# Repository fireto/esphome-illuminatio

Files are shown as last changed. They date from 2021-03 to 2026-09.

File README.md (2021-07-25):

# esphome-illuminatio
Dimmable LED drivers controller based on ESP Home with HomeAssistant integration via MQTT

in order to compile and deploy this project you need to get https://esphome.io

```podman run --rm -v "${PWD}":/config --device=/dev/ttyUSB0 -it esphome/esphome ./illuminatio.yml run```

BOM

LED Drivers connector cable:
 CS-DSDMDB15MM-010

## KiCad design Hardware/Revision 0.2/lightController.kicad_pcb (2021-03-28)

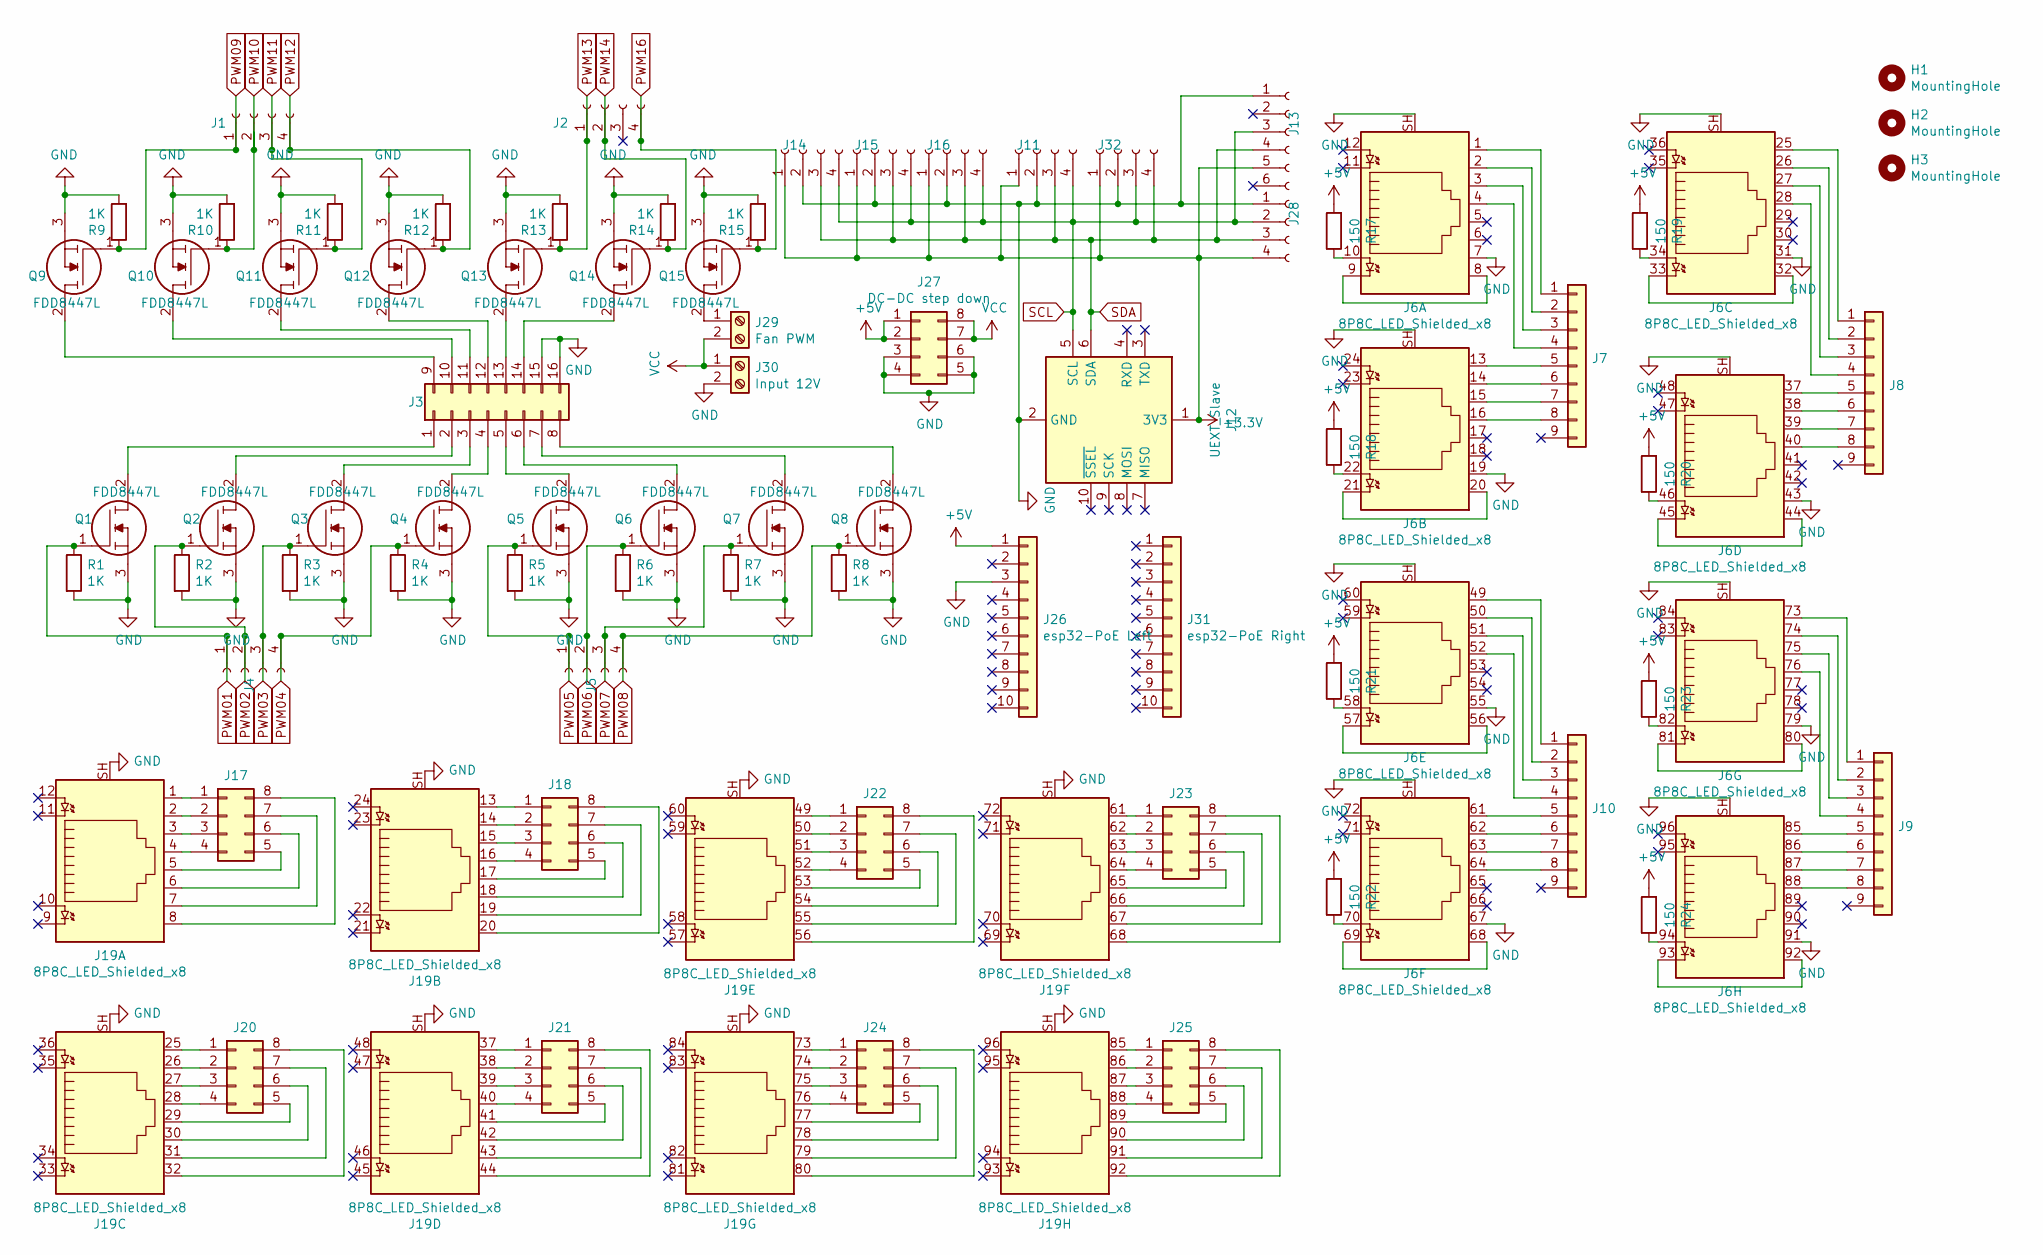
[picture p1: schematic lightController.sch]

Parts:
H1, H2, H3: MountingHole; MountingHole_3.2mm_M3
J1, J2, J4, J5: Conn_01x04_Female; PinSocket_1x04_P2.54mm_Vertical
J3: PWD_LED_Drivers; PinSocket_2x08_P2.54mm_Vertical
J6, J19: 8P8C_LED_Shielded_x8; RJ45_Chinesium_RJX-08
J7: PCF8574_1; PinSocket_1x09_P2.54mm_Vertical
J8: PCF8574_2; PinSocket_1x09_P2.54mm_Vertical
J9: PCF8574_4; PinSocket_1x09_P2.54mm_Vertical
J10: PCF8574_3; PinSocket_1x09_P2.54mm_Vertical
J11, J14, J15, J16: Conn_01x04_PCF8574; PinSocket_1x04_P2.54mm_Vertical
J12: UEXT_Slave; PinSocket_2x05_P2.54mm_Vertical
J13: Conn_01x06_PCA9685; PinSocket_1x06_P2.54mm_Vertical
J17: Port1; PinSocket_2x04_P2.54mm_Vertical
J18: Port2; PinSocket_2x04_P2.54mm_Vertical
J20: Port3; PinSocket_2x04_P2.54mm_Vertical
J21: Port4; PinSocket_2x04_P2.54mm_Vertical
J22: Port5; PinSocket_2x04_P2.54mm_Vertical
J23: Port6; PinSocket_2x04_P2.54mm_Vertical
J24: Port7; PinSocket_2x04_P2.54mm_Vertical
J25: Port8; PinSocket_2x04_P2.54mm_Vertical
J26: esp32-PoE Left; PinSocket_1x10_P2.54mm_Vertical
J27: DC-DC step down; MP1584EN_dc-dc_module
J28: i2c_extra; PinSocket_1x04_P2.54mm_Vertical
J29: Fan PWM; TerminalBlock_bornier-2_P5.08mm
J30: Input 12V; TerminalBlock_bornier-2_P5.08mm
J31: esp32-PoE Right; PinSocket_1x10_P2.54mm_Vertical
J32: BMP180; PinSocket_1x04_P2.54mm_Vertical
Q1, Q2, Q3, Q4, Q5, Q6, Q7, Q8, Q9, Q10, Q11, Q12, Q13, Q14, Q15: FDD8447L; Manufacturer_Part_Number FDD8447L; Mouser Part Number 512-FDD8447L
R1, R2, R3, R4, R5, R6, R7, R8, R9, R10, R11, R12, R13, R14, R15: 1K; R_0805_2012Metric
R17, R18, R19, R20, R21, R22, R23, R24: 150; R_0805_2012Metric

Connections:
+3V3: J11.1, J12.1 (3V3), J13.5, J14.1, J15.1, J16.1, J28.4, J32.1
+5V: J26.1, J27.1, J27.2, R17.2, R18.2, R19.2, R20.2, R21.2, R22.2, R23.2, R24.2
GND: J3.15, J3.16, J6.7, J6.19, J6.31, J6.43, J6.55, J6.67, J6.79, J6.91, J6.SH, J11.2, J12.2 (GND), J13.1, J14.2, J15.2, J16.2, J19.SH, J26.3, J27.3, J27.4, J27.5, J27.6, J28.1, J30.2, J32.2, Q1.3, Q2.3, Q3.3, Q4.3, Q5.3, Q6.3, Q7.3, Q8.3, Q9.3, Q10.3, Q11.3, Q12.3, Q13.3, Q14.3, Q15.3, R1.2, R2.2, R3.2, R4.2, R5.2, R6.2, R7.2, R8.2, R9.2, R10.2, R11.2, R12.2, R13.2, R14.2, R15.2
unnamed: J3.1, Q1.2
unnamed: J3.2, Q2.2
unnamed: J3.3, Q3.2
unnamed: J3.4, Q4.2
unnamed: J3.5, Q5.2
unnamed: J3.6, Q6.2
unnamed: J3.7, Q7.2
unnamed: J3.8, Q8.2
unnamed: J3.9, Q9.2
unnamed: J3.10, Q10.2
unnamed: J3.11, Q11.2
unnamed: J3.12, Q12.2
unnamed: J3.13, Q13.2
unnamed: J3.14, Q14.2
unnamed: J6.1, J7.1
unnamed: J6.2, J7.2
unnamed: J6.3, J7.3
unnamed: J6.4, J7.4
unnamed: J6.8, J6.9
unnamed: J6.10, R17.1
unnamed: J6.13, J7.5
unnamed: J6.14, J7.6
unnamed: J6.15, J7.7
unnamed: J6.16, J7.8
unnamed: J6.20, J6.21
unnamed: J6.22, R18.1
unnamed: J6.25, J8.1
unnamed: J6.26, J8.2
unnamed: J6.27, J8.3
unnamed: J6.28, J8.4
unnamed: J6.32, J6.33
unnamed: J6.34, R19.1
unnamed: J6.37, J8.5
unnamed: J6.38, J8.6
unnamed: J6.39, J8.7
unnamed: J6.40, J8.8
unnamed: J6.44, J6.45
unnamed: J6.46, R20.1
unnamed: J6.56, J6.57
unnamed: J6.58, R21.1
unnamed: J6.68, J6.69
unnamed: J6.70, R22.1
unnamed: J6.73, J9.1
unnamed: J6.74, J9.2
unnamed: J6.75, J9.3
unnamed: J6.76, J9.4
unnamed: J6.80, J6.81
unnamed: J6.82, R23.1
unnamed: J6.85, J9.5
unnamed: J6.86, J9.6
unnamed: J6.87, J9.7
unnamed: J6.88, J9.8
unnamed: J6.92, J6.93
unnamed: J6.94, R24.1
unnamed: J6.49, J10.1
unnamed: J6.50, J10.2
unnamed: J6.51, J10.3
unnamed: J6.52, J10.4
unnamed: J6.61, J10.5
unnamed: J6.62, J10.6
unnamed: J6.63, J10.7
unnamed: J6.64, J10.8
unnamed: J17.1, J19.1
unnamed: J17.2, J19.2
unnamed: J17.3, J19.3
unnamed: J17.4, J19.4
unnamed: J17.5, J19.5
unnamed: J17.6, J19.6
unnamed: J17.7, J19.7
unnamed: J17.8, J19.8
unnamed: J18.1, J19.13
unnamed: J18.2, J19.14
unnamed: J18.3, J19.15
unnamed: J18.4, J19.16
unnamed: J18.5, J19.17
unnamed: J18.6, J19.18
unnamed: J18.7, J19.19
unnamed: J18.8, J19.20
unnamed: J19.25, J20.1
unnamed: J19.26, J20.2
unnamed: J19.27, J20.3
unnamed: J19.28, J20.4
unnamed: J19.29, J20.5
unnamed: J19.30, J20.6
unnamed: J19.31, J20.7
unnamed: J19.32, J20.8
unnamed: J19.37, J21.1
unnamed: J19.38, J21.2
unnamed: J19.39, J21.3
unnamed: J19.40, J21.4
unnamed: J19.41, J21.5
unnamed: J19.42, J21.6
unnamed: J19.43, J21.7
unnamed: J19.44, J21.8
unnamed: J19.49, J22.1
unnamed: J19.50, J22.2
unnamed: J19.51, J22.3
unnamed: J19.52, J22.4
unnamed: J19.53, J22.5
unnamed: J19.54, J22.6
unnamed: J19.55, J22.7
unnamed: J19.56, J22.8
unnamed: J19.61, J23.1
unnamed: J19.62, J23.2
unnamed: J19.63, J23.3
unnamed: J19.64, J23.4
unnamed: J19.65, J23.5
unnamed: J19.66, J23.6
unnamed: J19.67, J23.7
unnamed: J19.68, J23.8
unnamed: J19.73, J24.1
unnamed: J19.74, J24.2
unnamed: J19.75, J24.3
unnamed: J19.76, J24.4
unnamed: J19.77, J24.5
unnamed: J19.78, J24.6
unnamed: J19.79, J24.7
unnamed: J19.80, J24.8
unnamed: J19.85, J25.1
unnamed: J19.86, J25.2
unnamed: J19.87, J25.3
unnamed: J19.88, J25.4
unnamed: J19.89, J25.5
unnamed: J19.90, J25.6
unnamed: J19.91, J25.7
unnamed: J19.92, J25.8
unnamed: J29.1, Q15.2
PWM01: J4.1, Q1.1, R1.1
PWM02: J4.2, Q2.1, R2.1
PWM03: J4.3, Q3.1, R3.1
PWM04: J4.4, Q4.1, R4.1
PWM05: J5.1, Q5.1, R5.1
PWM06: J5.2, Q6.1, R6.1
PWM07: J5.3, Q7.1, R7.1
PWM08: J5.4, Q8.1, R8.1
PWM09: J1.1, Q9.1, R9.1
PWM10: J1.2, Q10.1, R10.1
PWM11: J1.3, Q11.1, R11.1
PWM12: J1.4, Q12.1, R12.1
PWM13: J2.1, Q13.1, R13.1
PWM14: J2.2, Q14.1, R14.1
PWM16: J2.4, Q15.1, R15.1
SCL: J11.4, J12.5 (SCL), J13.3, J14.4, J15.4, J16.4, J28.2, J32.3
SDA: J11.3, J12.6 (SDA), J13.4, J14.3, J15.3, J16.3, J28.3, J32.4
VCC: J27.7, J27.8, J29.2, J30.1

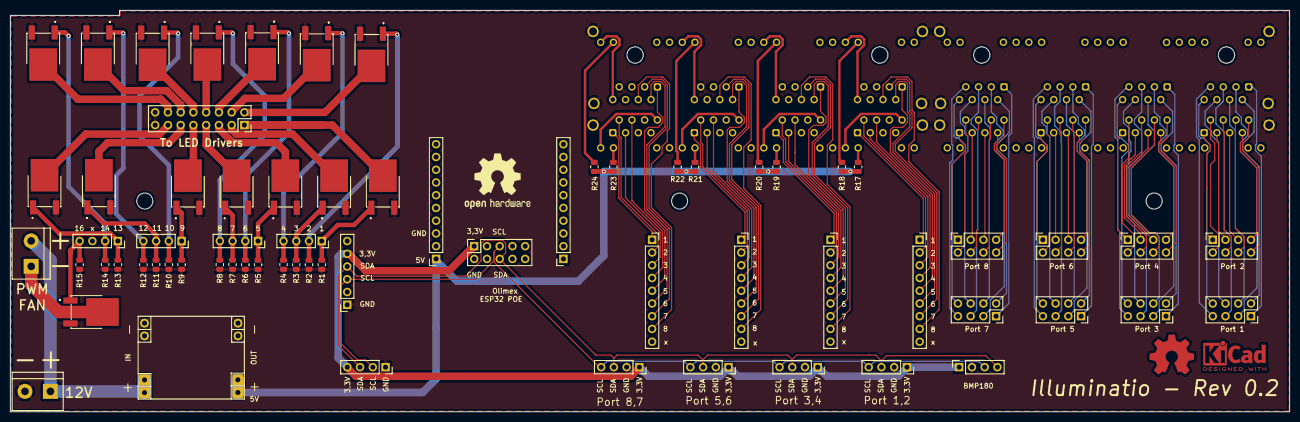
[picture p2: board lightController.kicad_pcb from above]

Board: 2 copper layers, 255.0 x 80.0 mm, 73 parts (0 on the bottom side), 148 nets.

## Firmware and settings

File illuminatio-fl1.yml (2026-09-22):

### Light controller main
substitutions:
  devicename: fl1illuminatio
  upperDevicename: Floor1 Lights Controller
  domainName: '.vn.fireto.net'   # domain name for the microcontroller
  # <<: !include ioMapping.yml
  <<: !include fl1SwitchMapping.yml

esphome:
  name: $devicename

esp32:
  board: esp32-poe
  framework:
       type: esp-idf

packages:
  # wifi: !include common/wifi.yml
  ethernet: !include common/ethernet.yml
  api: !include common/api.yml
  ota: !include common/ota.yml
  # mqtt: !include common/mqtt.yml
  logger: !include common/logger.yml
  time: !include common/time.yml
  webserver: !include common/webserver.yml
  # btproxy: !include common/btproxy.yml

i2c:
  scan: True

# esp32_ble_tracker:
#   scan_parameters:
#     interval: 1100ms
#     window: 1100ms
#     active: true

# bluetooth_proxy:

# load module for PCF8574 Remote 8-Bit I/O Expanderfor I2C Bus
# datasheet https://www.ti.com/lit/ds/symlink/pcf8574.pdf
pcf8574:
  - id: 'pcf8574_1'
    address: 0x38
    pcf8575: False

  - id: 'pcf8574_2'
    address: 0x39
    pcf8575: False

  - id: 'pcf8574_3'
    address: 0x3A
    pcf8575: False

  - id: 'pcf8574_4'
    address: 0x3B
    pcf8575: False

  # - id: 'pcf8574_1'
  #   address: 0x20
  #   pcf8575: False

  # - id: 'pcf8574_2'
  #   address: 0x21
  #   pcf8575: False

  # - id: 'pcf8574_3'
  #   address: 0x22
  #   pcf8575: False

  # - id: 'pcf8574_4'
  #   address: 0x23
  #   pcf8575: False

# Individual outputs
button:
  - platform: restart
    name: $upperDevicename Restart

  # Trigger open study door action
  - platform: template
    name: Open Front door
    id: doorFrontOpen
    on_press:
      - switch.turn_on: fl1HallwayFrontDoor
      - delay: 2s
      - switch.turn_off: fl1HallwayFrontDoor

# On/off loads (relays) exposed as switches instead of lights
switch:
  - platform: output
    name: "fl1HallwayFrontDoor"
    id: fl1HallwayFrontDoor
    output: pca1_1
    restore_mode: RESTORE_DEFAULT_OFF

  - platform: output
    name: "fl1WaterHeater"
    id: fl1WaterHeater
    output: pca1_4
    restore_mode: RESTORE_DEFAULT_OFF
      
      # Temp sensor
sensor:
  - platform: bmp085
    temperature:
      name: "$upperDevicename enclosure Temperature"
    pressure:
      name: "$upperDevicename enclosure Pressure"
    # 60s, not 300s. This probe is the rack fan thermostat's control input, and
    # the rack cools with a time constant of about 13 min. At 300s that is only
    # 2.6 samples per time constant, which is too coarse for a proportional
    # loop. 60s gives about 13. The BMP180 is low power and does not self-heat
    # measurably at this rate.
    update_interval: 60s
    
#   - platform: uptime
#     name: Uptime Sensor
#     id: uptime_sensor
#     update_interval: 60s
#     internal: true
#     on_raw_value:
#       then:
#         - text_sensor.template.publish:
#             id: uptime_human
#             state: !lambda |-
#               int seconds = round(id(uptime_sensor).raw_state);
#               int days = seconds / (24 * 3600);
#               seconds = seconds % (24 * 3600);
#               int hours = seconds / 3600;
#               seconds = seconds % 3600;
#               int minutes = seconds /  60;
#               seconds = seconds % 60;
#               return (
#                 (days ? String(days) + "d " : "") +
#                 (hours ? String(hours) + "h " : "") +
#                 (minutes ? String(minutes) + "m " : "") +
#                 (String(seconds) + "s")
#               ).c_str();

# text_sensor:
#   - platform: template
#     name: $upperDevicename Uptime Human Readable
#     id: uptime_human
#     icon: mdi:clock-start
              
# load module for PCA9685 16-Channel 12-bit PWM/Servo Driver I2C
# datasheet https://www.nxp.com/docs/en/data-sheet/PCA9685.pdf
pca9685:
  - frequency: 500
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

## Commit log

2021-03-19 Initial structure + ealry settings for hallwaySwitch
    [switch_mapping.ods]
2021-03-28 Adding hardware KiCad project
    [lightController-B_Cu.gbr, lightController-B_Mask.gbr, lightController-B_SilkS.gbr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]
2021-03-28 Adding functionality to limit min PWM, as driver does start at PWD < 40%
    [switch_mapping.ods]
2021-03-31 Adding BMP180 temperature sensor inside the enclosure
2021-07-25 Updating switch_mapping.ods
    [switch_mapping.ods]
2021-08-17 update I/O mapping
    [switch_mapping.ods]
2021-08-17 fialize switch behaviour for floor 1
2021-10-23 floor1 rc1 , switch logging Verbose -> Debug
    [switch_mapping.ods]
2021-10-23 moving switch - light mapping to external file: fl1SwitchMapping.yml
2021-10-30 renaming all switches and lights on floor2 to have fl2 prefix
    [switch_mapping.ods]
2021-10-30 renaming all switches and lights on floor1 to have fl1 prefix. Adding max dimming value.
2022-09-29 remap keys: remove fl1BathroomShower, individual control living room ceiling 3 drivers
    [switch_mapping.ods]
2022-09-29 FL1: disable API, configrure min-max dimming in Output, add UptimeHumanReadable, remove transition time for switches, apply rempapped rules, cahnge min-max dimming as now we use 100% of the range
2022-10-17 FL2: disable API, configrure min-max dimming in Output, add UptimeHumanReadable, remove transition time for switches, apply rempapped rules, cahnge min-max dimming as now we use 100% of the range
2023-07-21 Enable EspHome API, rename devices
2023-09-19 Add relay output for fron door lock, reconfigure relay outputs as binary light
    [switch_mapping.ods]
2025-03-07 Enable OTA updates with ESPHome platform, update web server version, and refactor ESP32 platform declaration in configuration files
2026-06-11 Convert water heater and front door lock to output switches, rename floor heating to water heater, fix deprecated ethernet clk_mode
    [illuminatio-fl1.yml]
2026-07-16 illuminatio-fl2: pin framework type esp-idf explicitly (match fl1; ESPHome 2026.7 toolchain default change)
2026-08-31 Make the case fan a fan, not a light
    As a monochromatic light the case fan landed in the light domain, and
    turnOffAllTheLighs targets floor_id [yard, floor1, floor2]. So every goodNight
    switched the case fan off with the lights. That removed the cooling silently,
    and it biased the BMP180, which sits in the same enclosure and is the probe
    the rack fan thermostat depends on.
    fan: platform: speed takes the same pca9685 float output, the way RackIpPower
    drives its ledc output. restore_mode is RESTORE_DEFAULT_ON, so a reboot
    returns the cooling rather than leaving it off.
    Nothing references the old light entities. Both configs validate on 2026.8.1.
    Not flashed.
    [illuminatio-fl1.yml, illuminatio-fl2.yml]
2026-08-31 Read the BMP180 every 60s instead of every 300s
    The enclosure probe is the control input for the rack fan thermostat. The
    rack cools with a time constant of about 13 min, so 300s gives only 2.6
    samples per time constant, which is too coarse for a proportional loop. 60s
    gives about 13. The BMP180 is low power and does not self-heat at this rate.
    Bundled with the case fan domain change, because both need the same flash and
    that flash turns on every light on the floor.
    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
2026-09-20 Require a 2 s hold on the bathroom key 4
    A bare on_press let a palm or a lean on the panel close the boiler
    relay. On 01.09.2026 a press closed it for 59 h, because a latched
    boiler_fault kept HA out of the relay. The key stays as the manual
    override for the case that HA is down. It now needs a deliberate
    gesture. The config validates on ESPHome 2026.9.0. The change takes
    effect at the next flash.
    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
2026-09-22 Silence the GPIO12 strapping pin warning on the PHY power pin
